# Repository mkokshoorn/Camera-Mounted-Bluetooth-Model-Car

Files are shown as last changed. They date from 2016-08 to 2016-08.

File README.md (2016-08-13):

# Camera Mounted Bluetooth Model Car

Embedded systems six-person project (known as "Wacky Racers") to design and implement a camera mounted, Bluetooth controlled, model car. The project had a requirement that three separate 4-layer boards were developed each with their own microcontroller and communicating over a common I2C bus. An STM32F4 microcontroller was selected for the project.

## Motor Control / Power Board
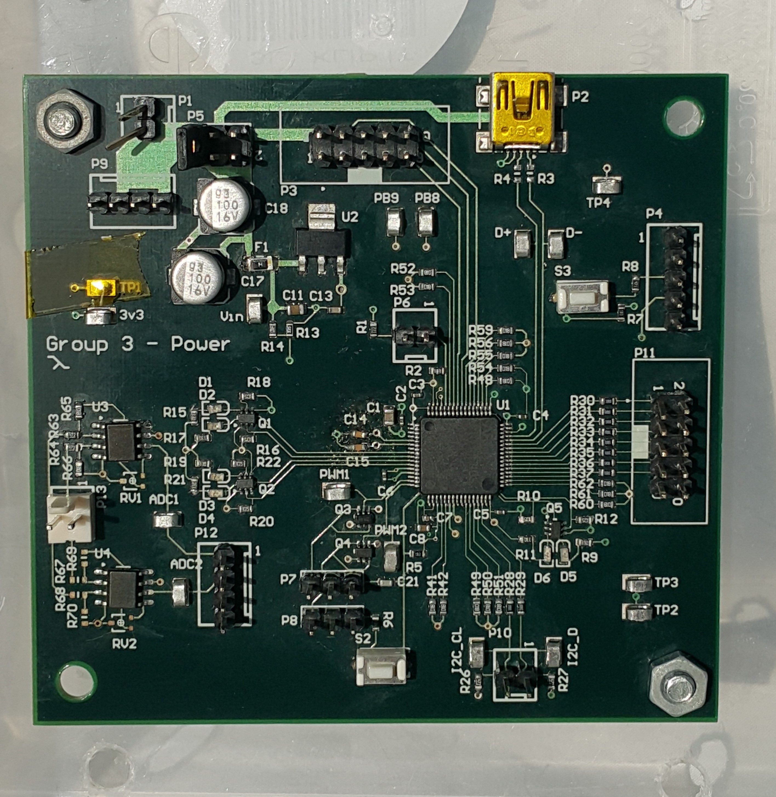
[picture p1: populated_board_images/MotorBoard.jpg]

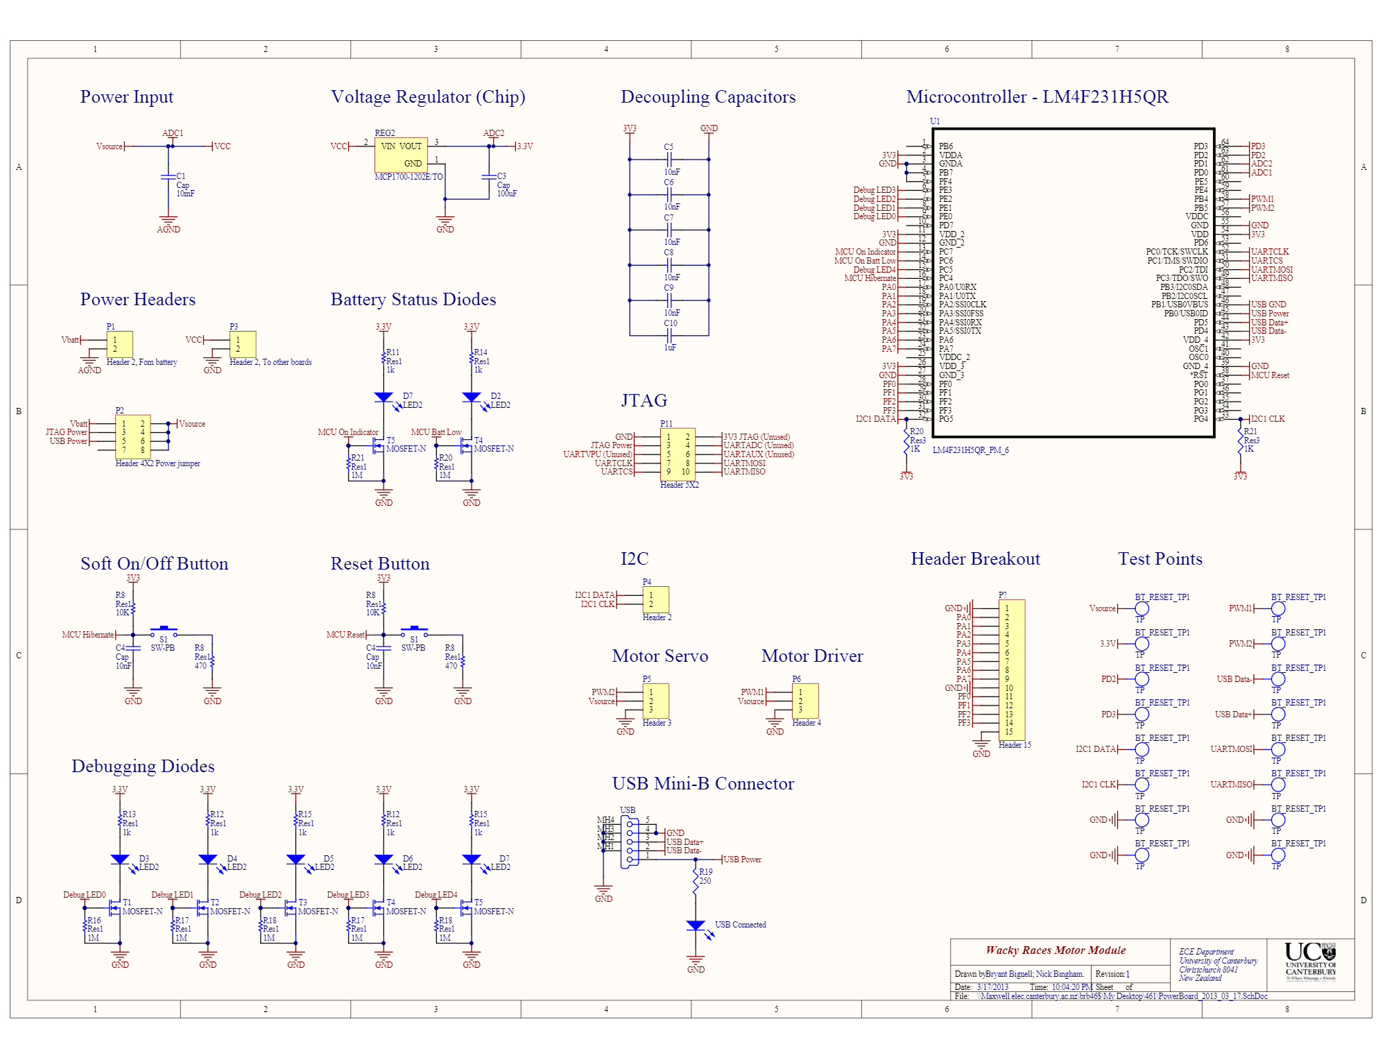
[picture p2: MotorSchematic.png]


## Camera Board
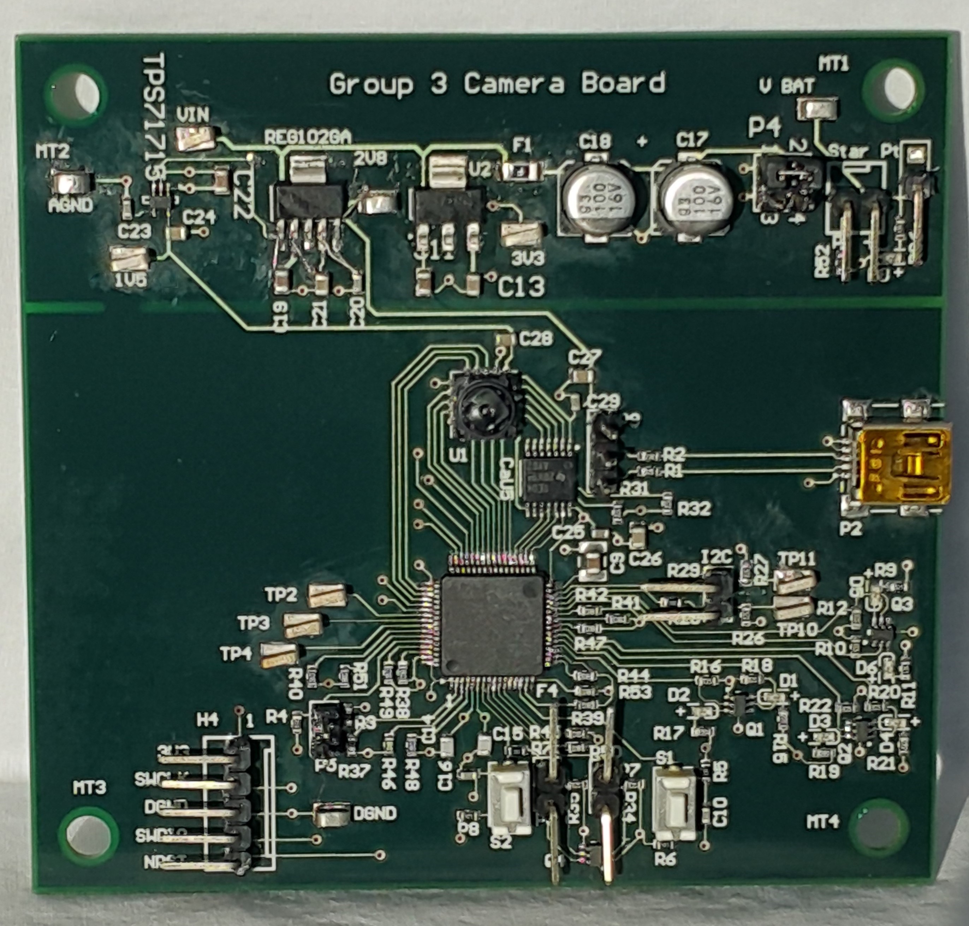
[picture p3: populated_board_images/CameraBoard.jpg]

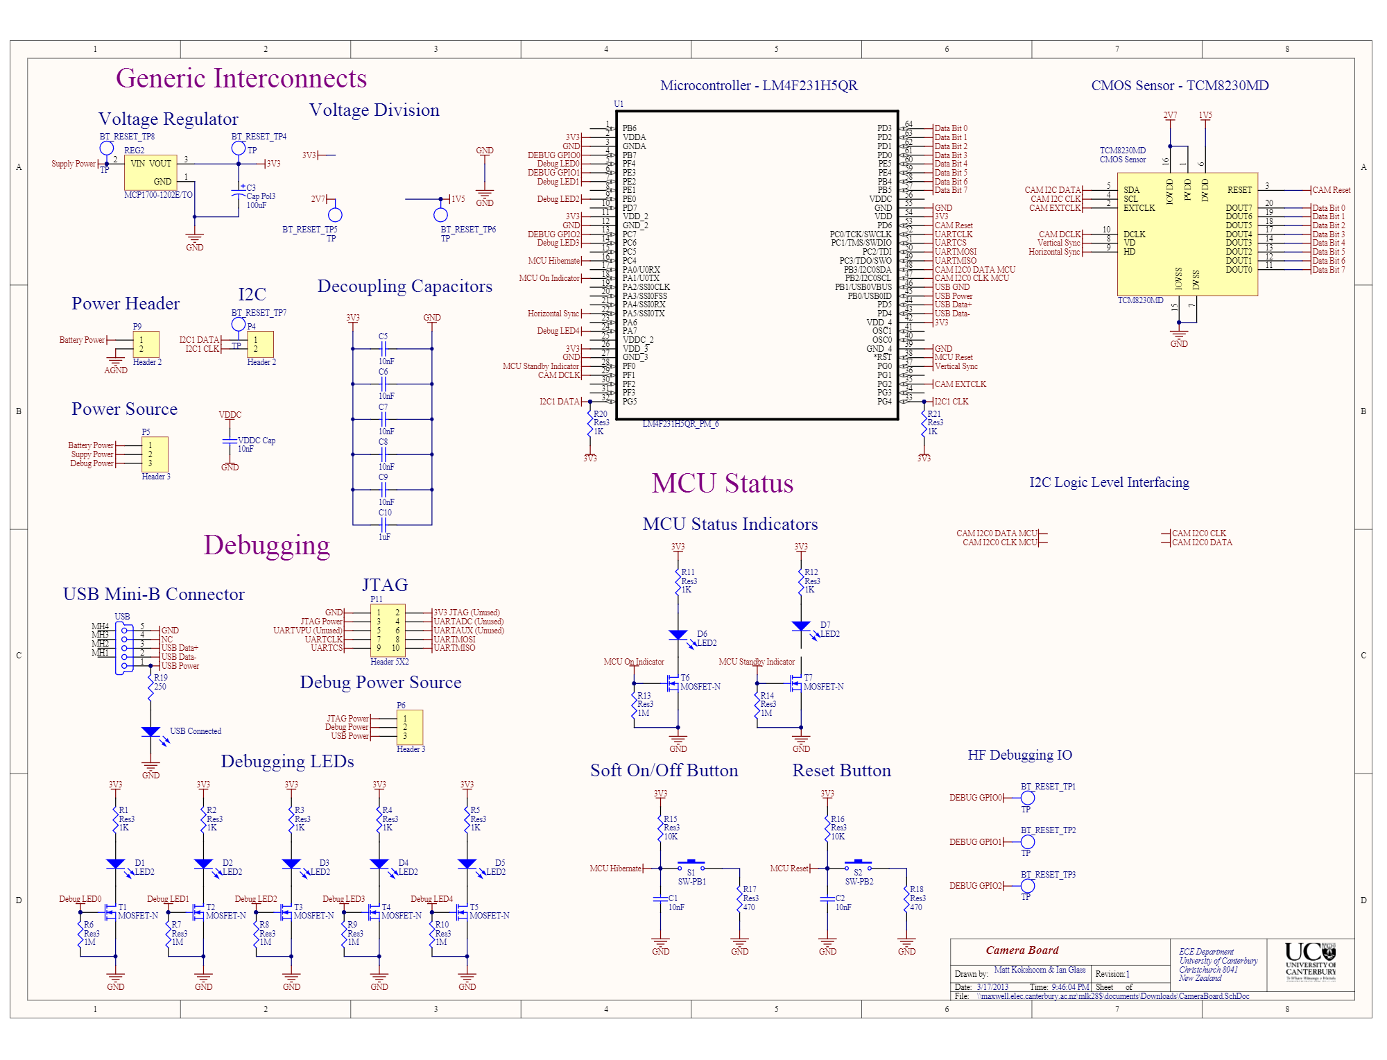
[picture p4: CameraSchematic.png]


## Communications Board
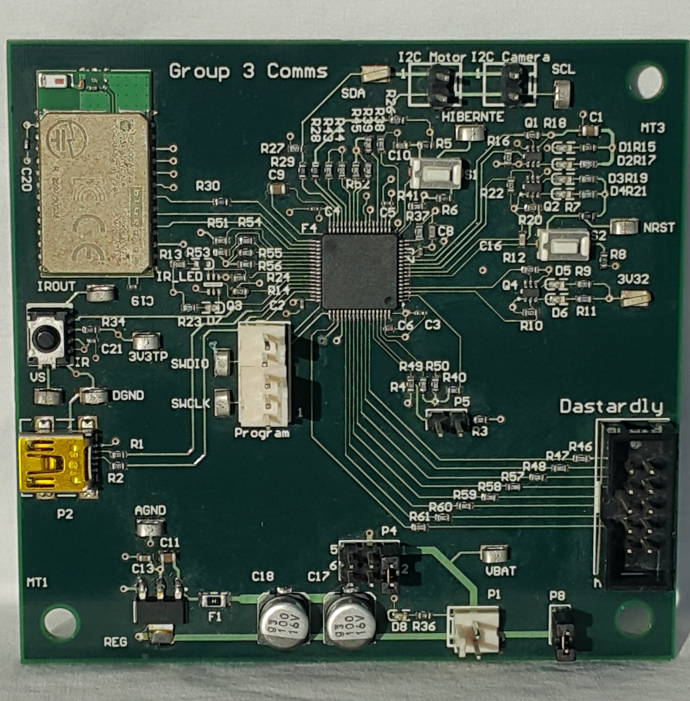
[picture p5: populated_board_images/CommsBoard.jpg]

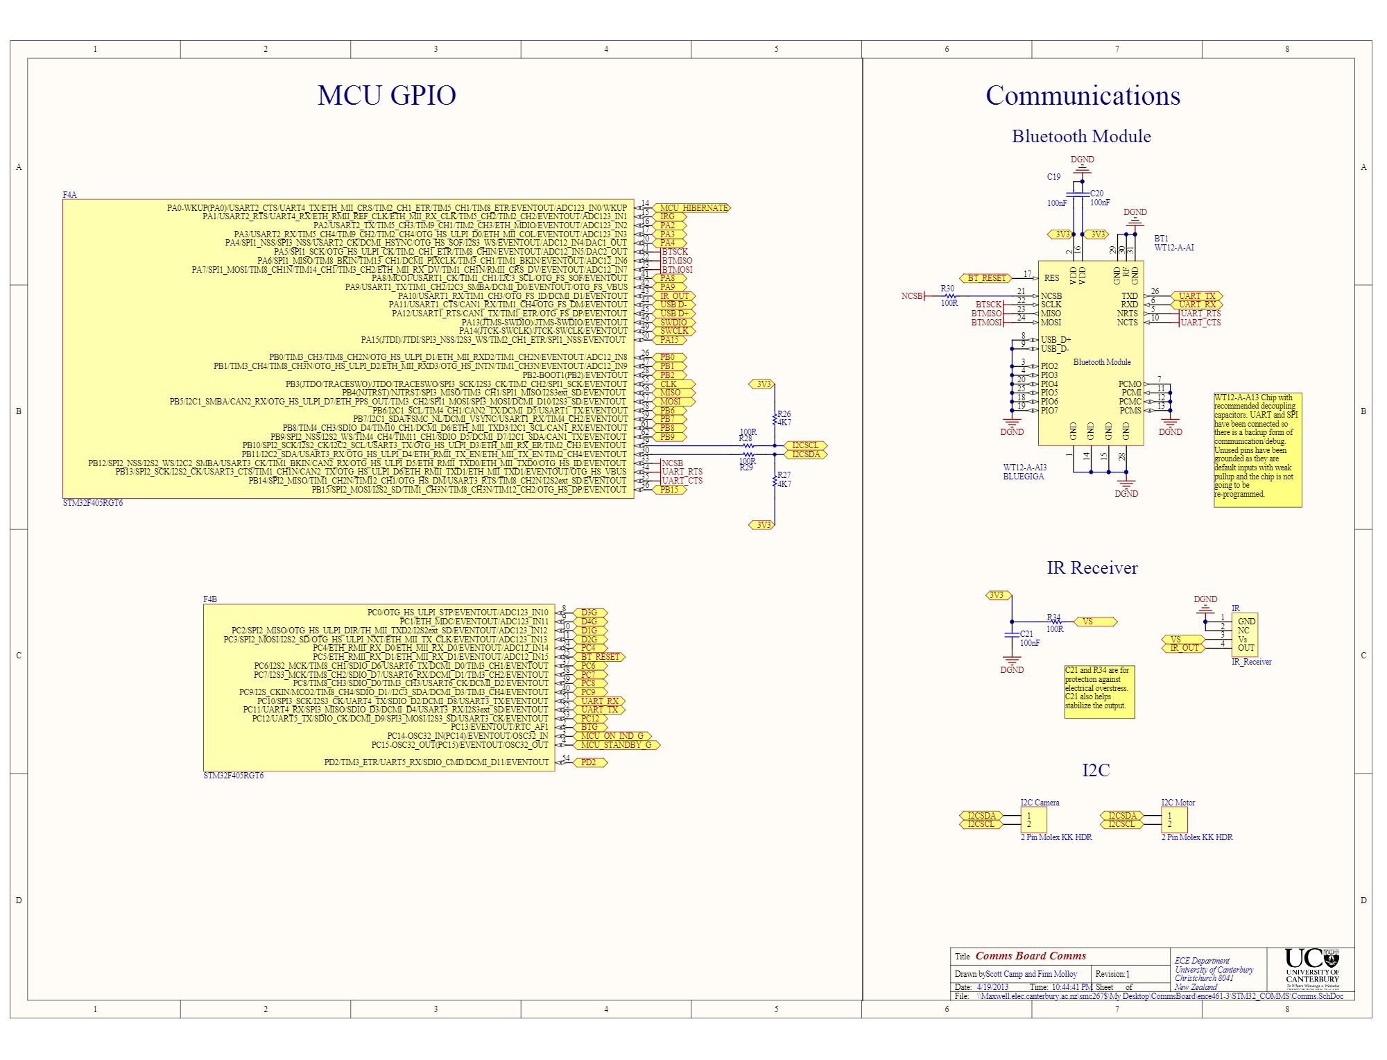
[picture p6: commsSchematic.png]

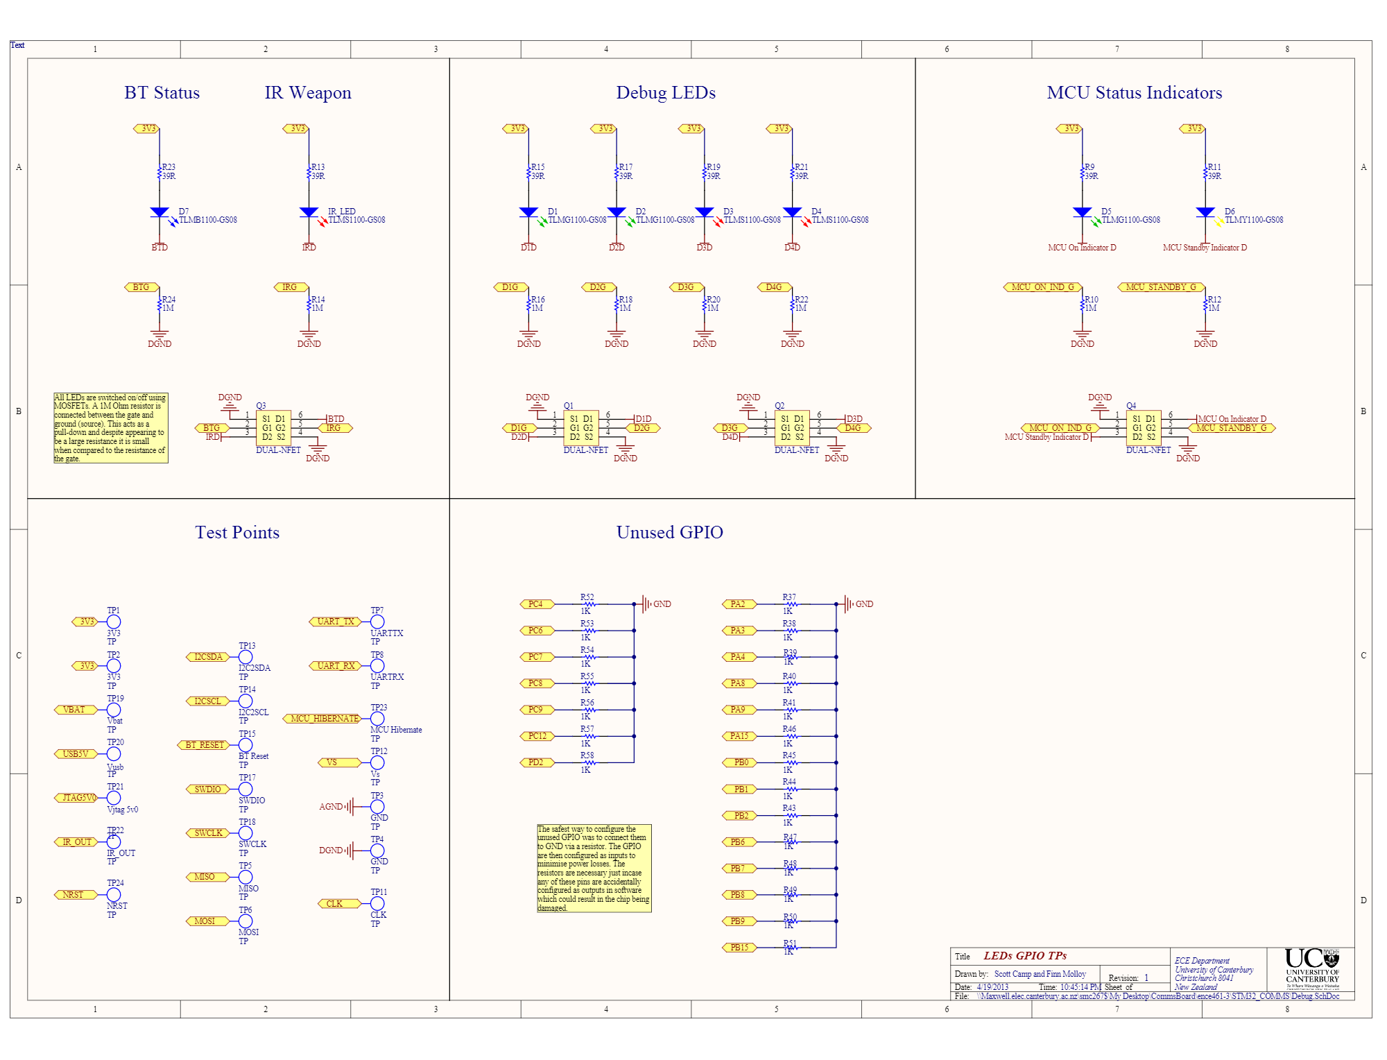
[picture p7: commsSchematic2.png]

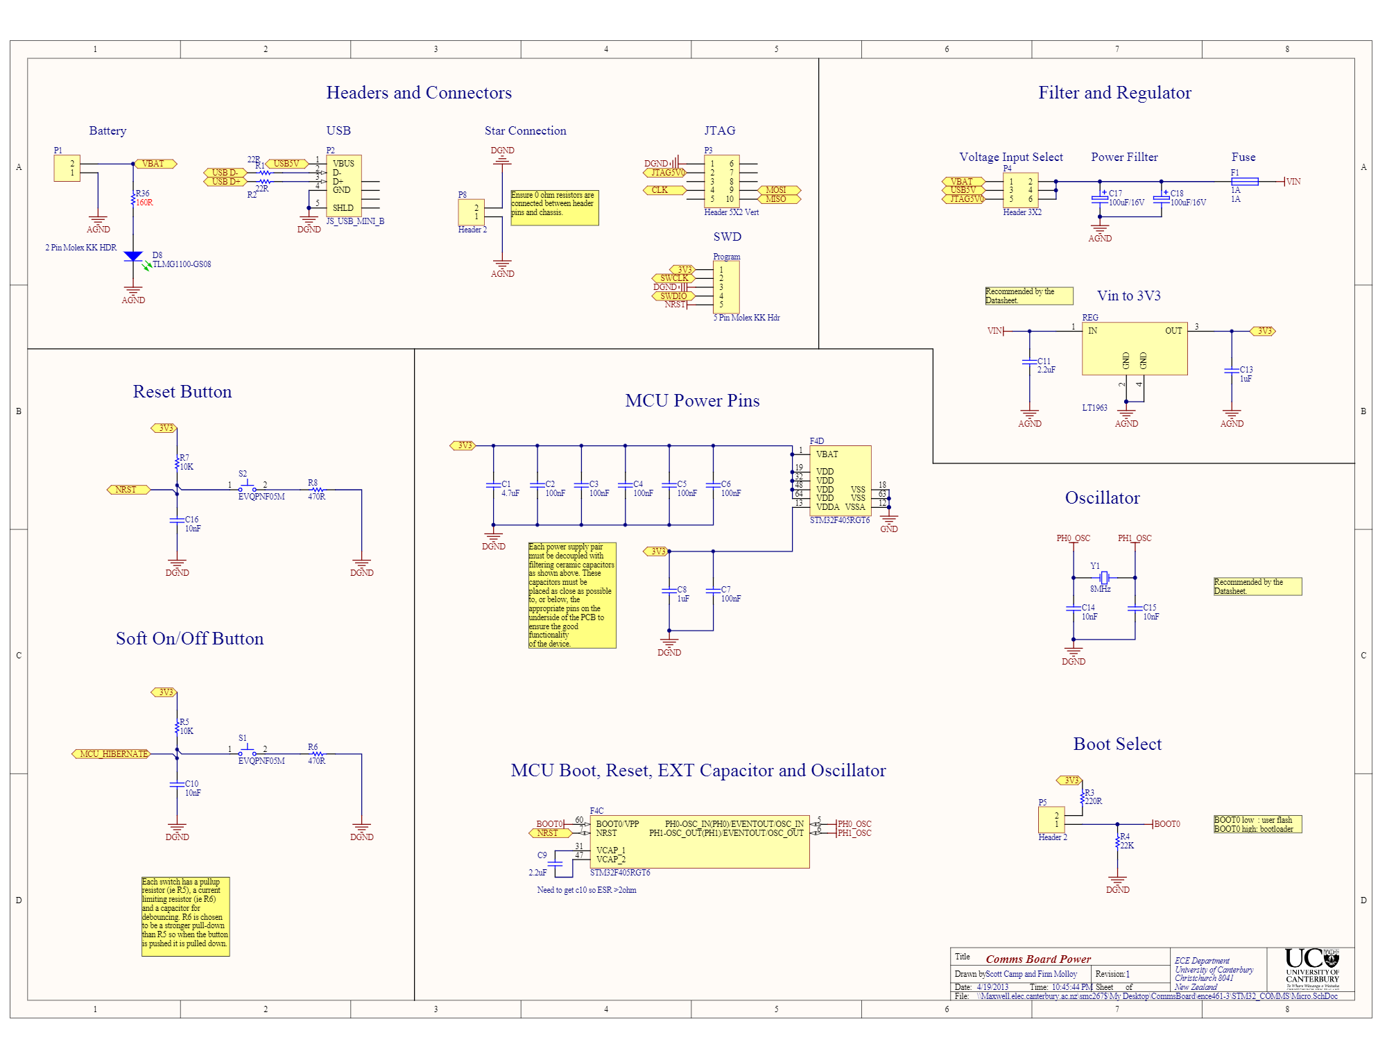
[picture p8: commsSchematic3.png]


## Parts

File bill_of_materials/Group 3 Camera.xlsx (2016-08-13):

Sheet: BOM Report
Bill of Materials |  |  | Camera Board
Source Data From: |  | CameraBoard.SchDoc
Project: |  | Wacky Racers
Variant: |  | None
Creation Date: | 4/4/2013 | 9:10:37 PM
Print Date: | 2013-04-04 | 22:50:31
Production Quantity: | 1
Currency | <none>
Footprint | Comment | LibRef | Designator | Description | Quantity | #Column Name Error:Supplier | Supplier 1 | Supplier Part Number 1
DSO-F2/D6.1 | LED2 | LED2 | D1, D2, D3, D4, D5 | Red LED | 5 |  | Digi-Key | VLMS1300-GS08
TO-92-TO3 | 3V3 Regulator | MCP1700-1202E/TO | REG1 | Low Quiescent Current LDO, 3-Pin TO-92, Extended TemperatureBAG | 1 |  | Digi-Key
 | 2V8 Regulator | NCP502 | REG2 |  | 1 |  | Digi-Key
 | 1V5 Regulator |  | REG3 |  | 1 |  | Digi-Key
BCY-W3/B.8 | MOSFET-N | MOSFET-N | T1, T2, T3, T4, T5,T6 | N-Channel MOSFET | 3 |  | Digi-Key | SI1970DH-T1-E3CT-ND
481900001 | 0481900001 | 0481900001 | USB | USB On-The-Go (OTG) Mini-B Receptacle, Right Angle, SMT, 0.80mm (.031") Pitch, Solder Tabs with Back Cover, Recessed Type | 1 |  | Digi-Key | A31727CT-ND
3.5X2.8X1.9 | LED3 | LED3 | USB Connected/MCU Status | Green LED | 2 |  | Digi-Key | VLMTG1300-GS08
TODO | OSC | OSC | Y1 | Oscillator | 1 |  | Digi-Key | 535-10088-2-ND
C1210 | Cap Semi | Cap Semi | C1, C2, C5, C6, C7, C8, C9, C10, C11, C12, C13, C14, C15, C16, VDDC Cap | Capacitor (Semiconductor SIM Model) | 15 |  | ECE Dept Stock
C0805 | Cap Pol3 | Cap Pol3 | C3, C17, C17 | Polarized Capacitor (Surface Mount) | 3 |  | ECE Dept Stock
HDR1X2 | Header 2 | Header 2 | I2C Header, PWR Header | Header, 2-Pin | 2 |  | ECE Dept Stock
J1-0603 | Res3 | Res3 | R1, R2, R3, R4, R6, R7, R8, R9, R11, R12, R13, R14, R15, R16, R17, R18, R19, R20, R21 | Resistor | 19 |  | ECE Dept Stock
PM64 | LM4F231H5QR_PM_6 | LM4F231H5QR_PM_6 | U1 | Cortex M4 | 1 |  | Element 14 | 2246242
TODO | Logic Shifter | LS1 | LS1 | Logic Inteface between Camera and MCU | 1 |  | Element 14 | TXS0104ED
FSM2JSMA | Switch | SW_FSM2JSMA | SW1, SW2 | TE CONNECTIVITY / ALCOSWITCH - FSM2JSMA - SWITCH, SPST, 0.05A, 24VDC, SMD | 2 |  | Farnell | 3801287
TCM8230MD | TCM8230MD | TCM8230MD | U? | Toshiba I2C Camera | 1 |  | Spark Fun
 |  |  |  |  | 56
Approved |  | Notes

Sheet: Project Information
Project Full Path | Free Documents
Project Filename | Free Documents
Variant Name | None
Data-Source Filename | CameraBoard (1).SchDoc
Data-Source Full Path | \\Maxwell.elec.canterbury.ac.nz\mlk28$\My Desktop\CameraBoard (1).SchDoc
Title | Camera Board
Total Quantity | 63
Report Time | 9:10:37 PM
Report Date | 4/4/2013
Report Date & Tine | 4/4/2013 9:10:37 PM
Output Name | Bill of Materials
Output Type | BOM_PartType
Output Generator Name | BOM
Output Generator Description | Bill of Materials

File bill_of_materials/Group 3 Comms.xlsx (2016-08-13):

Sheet: BOM Report
Bill of Materials |  |  | Comms Microcontroller and General
Source Data From: |  | WackyRacersComms.PrjPcb
Project: |  | WackyRacersComms.PrjPcb
Variant: |  | None
Creation Date: | 4/4/2013 | 8:41:36 PM
Print Date: | 2013-04-04 | 20:59:11
Production Quantity: | 1
Currency | <none>
Footprint | Comment | LibRef | Designator | Description | Quantity | Supplier 1 | Supplier Part Number 1 | Supplier 2 | Supplier Part Number 2 | Manufacturer | Manufacturer PN
WT12_Bluetooth | BT Chip | UN_WT12_Bluetooth | BT1 | BLUEGIGA - WT12-A-AI - BLUETOOTH MOD, V2.1, CLASS 2, 3MBPS | 1 | Farnell | 1704779 |  |  | BLUEGIGA
C1210 | Cap Semi | Cap Semi | C1, C2, C4, C5, C6, C7, C8, C9, C10, C11, C12, C13, C14, C15 | Capacitor (Semiconductor SIM Model) | 14 | ECE Dept Stock
C0805 | Cap Pol3 | Cap Pol3 | C3 | Polarized Capacitor (Surface Mount) | 1 | ECE Dept Stock
HDR1X3 | Header 3 | Header 3 | Debug Header, SRC Header | Header, 3-Pin | 2 | ECE Dept Stock
TODO | Green LED | Green LED | GREEN_LED-1, GREEN_LED-2, GREEN_LED-3, GREEN_LED-4, GREEN_LED-5, GREEN_LED-6, GREEN_LED-7, GREEN_LED-8, GREEN_LED-9 | GREEN_LED | 9 | Digi-Key | VLMTG1300-GS08 |  |  | Vishay | VLMTG1300-GS08
HDR1X2 | Header 2 | Header 2 | I2C Header, PWR Header | Header, 2-Pin | 2 | ECE Dept Stock
DSO-F2/D6.1 | IR Led | IRLed | IR LED | Typical RED, GREEN, YELLOW, AMBER GaAs LED | 1 | ECE Dept Stock
TODO | IR | IR | IR Reveiver | IR | 1 | Element 14 | 2251351 |  |  | Vishay | TSOP35438TR
HDR2X5 | Header 5X2 | Header 5X2 | JTAG Header | Header, 5-Pin, Dual row | 1 | ECE Dept Stock
PM64 | LM4F231H5QR_PM_6 | LM4F231H5QR_PM_6 | Micro_1 | M4 Microcontroller | 1 | Element 14 | 2246242 |  |  | Texas Instruments | LM4F231H5QRFIG
TODO | DUAL N-FET | ALD110814SCL | N-FET-1, N-FET-2, N-FET-3, N-FET-4 | QUAD N-FET | 4 | Digi-key | SI1970DH-T1-E3CT-ND
J1-0603 | Res3 | Res3 | R1, R2, R3, R4, R6, R7, R8, R9, R11, R12, R13, R14, R15, R16, R17, R18, R19, R20, R21, R22, R23, R24, R25, R26 | Resistor | 24 | ECE Dept Stock
TODO | 3V3 Regulator | 3V3 Reg | Reg | 3V3 Regulator | 1 | Digi-Key | 296-11021-1-ND
FSM2JSMA | Switch | SW_FSM2JSMA | SW1, SW2 | TE CONNECTIVITY / ALCOSWITCH - FSM2JSMA - SWITCH, SPST, 0.05A, 24VDC, SMD | 2 | Farnell | 3801287 | Digi-Key | 450-1757-6-ND | TE CONNECTIVITY / ALCOSWITCH
TODO | OSC | OSC | Y1 | Oscillator | 1 | Digi-Key | 535-10088-2-ND |  |  | Abracon Corporation | ASV-60.000MHZ-E-T
481900001 | USB-MINI_B | 0481900001 | USB | USB On-The-Go (OTG) Mini-B Receptacle, Right Angle, SMT, 0.80mm (.031") Pitch, Solder Tabs with Back Cover, Recessed Type | 1 | Digi-Key | A31727CT-ND
 |  |  |  |  | 66
Approved |  | Notes

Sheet: Project Information
Project Full Path | \\Maxwell.elec.canterbury.ac.nz\smc267$\My Desktop\ENEL461\WackyRacersComms.PrjPcb
Project Filename | WackyRacersComms.PrjPcb
Variant Name | None
Data-Source Filename | WackyRacersComms.PrjPcb
Data-Source Full Path | \\Maxwell.elec.canterbury.ac.nz\smc267$\My Desktop\ENEL461\WackyRacersComms.PrjPcb
Title | Comms Microcontroller and General
Total Quantity | 63
Report Time | 8:41:36 PM
Report Date | 4/4/2013
Report Date & Tine | 4/4/2013 8:41:36 PM
Output Name | Bill of Materials
Output Type | BOM_PartType
Output Generator Name | BOM
Output Generator Description | Bill of Materials

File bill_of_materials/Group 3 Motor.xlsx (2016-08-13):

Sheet: BOM Report
Bill of Materials |  |  | Wacky Races Motor Module
Source Data From: |  | PowerBoard_bryant_2013_04_04.SchDoc
Project: |  | Free Documents
Variant: |  | None
Creation Date: | 4/4/2013 | 7:29:26 PM
Print Date: | 2013-04-04 | 20:43:14
Production Quantity: | 1
Currency | <none>
Footprint | Comment | LibRef | Designator | Description | Quantity | #Column Name Error:Supplier | Supplier 1 | Supplier Part Number 1 | Supplier 2 | Supplier Part Number 2 | #Column Name Error:Manufacturer | #Column Name Error:Manufacturer PN
RAD-0.3 | Cap | Cap | C1, C3, C4, C4 | Capacitor | 4 |  | ECE Dept Stock | _
0805 | Cap Semi | Cap Semi | C5, C6, C7, C8, C9, C10 | Capacitor (Semiconductor SIM Model) | 6 |  | ECE Dept Stock | _
DSO-F2/D6.1 | LED2 | LED2 | D1, D2, D3, D4, D5, D6, D7 | Typical RED, GREEN, YELLOW, AMBER GaAs LED | 6 |  | Digi-Key | VLMB1300-ND
HDR1X2 | Header 2, Fom battery | Header 2 | P1, P2, P3, P4, P5, P6, P7, P11 | Header | 8 |  | ECE Dept Stock | _
1206 | Res1 | Res1 | R8, R8, R8, R8, R8, R8, R11, R12, R12, R13, R14, R15, R16, R17, R17, R18, R20, R21 | Resistor | 18 |  | ECE Dept Stock | _
RAD-0.3 | Res3 | Res3 | R19, R20, R21 | Resistor | 3 |  | ECE Dept Stock | _
TO-92-TO3 | MCP1700-1202E/TO | MCP1700-1202E/TO | REG2 | Low Quiescent Current LDO, 3-Pin TO-92, Extended TemperatureBAG | 1 |  | Digi-Key | 296-11021-1-ND
SPST-2 | SW-PB | SW-PB | S1, S2 | Switch | 2 |  | Digi-Key | 450-1130-ND
SC-70 | MOSFET-N | MOSFET-N | T7, T8 | Complementary Low-Threshold MOSFET Pair | 2 |  | Digi-Key | SI1555DL-T1-E3CT-ND
BCY-W3/B.8 | MOSFET-N | MOSFET-N | T1, T2, T3, T4, T5, T6, | DUAL N-CHANNEL | 2 |  | Digi-Key | SI1970DH-T1-E3CT-ND
E3 | MOSFET-P | MOSFET-P | T9, T10 | P-Channel MOSFET | 0 |  | Digi-Key | SI1555DL-T1-E3CT-ND
 | OSCILLATOR | OSCILLATOR | K1 | OSCILLATOR | 1 |  | Digi-Key | 535-10088-2-ND
PM64 | LM4F231H5QR_PM_6 | LM4F231H5QR_PM_6 | U1 | CORTEX M4 | 1 |  | ELEMENT14 | 2246424
USB | 0481900001 | 0481900001 | USB | USB On-The-Go (OTG) Mini-B Receptacle, Right Angle, SMT, 0.80mm (.031") Pitch, Solder Tabs with Back Cover, Recessed Type | 1 |  | Digi-Key | A31727CT-ND
 |  |  |  |  | 55
Approved |  | Notes

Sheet: Project Information
Project Full Path | Free Documents
Project Filename | Free Documents
Variant Name | None
Data-Source Filename | PowerBoard_bryant_2013_04_04.SchDoc
Data-Source Full Path | \\Maxwell.elec.canterbury.ac.nz\brb46$\My Desktop\461\PowerBoard_bryant_2013_04_04.SchDoc
Title | Wacky Races Motor Module
Total Quantity | 61
Report Time | 7:29:26 PM
Report Date | 4/4/2013
Report Date & Tine | 4/4/2013 7:29:26 PM
Output Name | Bill of Materials
Output Type | BOM_PartType
Output Generator Name | BOM
Output Generator Description | Bill of Materials

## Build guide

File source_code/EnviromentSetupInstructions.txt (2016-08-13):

1) Download Attolic Embedded Workbench (This is used for programming/debugging via the SWD link)
	http://www.atollic.com/index.php/download/truestudio-for-arm 

	- Open Appropriate Workspace I have set up.

		- Comms
		- Camera
		- Motor 
		- Dev Board

Programming Hardware setup:

	- Grab a Dev board and some female to female cords (got heaps)
	- Find the SWD header 6 pin header (Calling the end with the dot 1):

		from Dev board to Wacky Racers boards:
		- Pin 1/??? 	to ??? (Dev Board:GND)    ------- N/A
		- Pin 2/T_JTCK 	to SWCLK (Dev Board:PA14)
		- Pin 3/GND	to DGND (Dev Board:GND)
		- Pin 4/T_JTMS  to SWDIO (Dev Board:PA13)
		- Pin 5/T_NRST 	to NRST (Dev Board:NRST)
		- Pin 6/T_SWO 	to GND (Dev Board:PB3)    ------- N/A

2) Download and Install Tera Term (This is used for uart communication with the chip)
	- Go New Connection -> Serial Connection -> USB Serial Port (COMX)
	- Setup -> Serial Port Baud Rate -> 115200 .
	- Setup -> Terminal -> Make syre recieve and transmit are 'CR' under new-line and encavble local echo.

	To Enable Serial Comms with MCU enter the following in the terminal (By \n I mean enter) 'm\n','3\n','9\n','1\n','1\n','2\n' then '(2)'

	Ensure the following hardware Hardware- Connection (DEV BOARD) to Bus Pirate 
		- MISO (bus Pirate) to PA2 (Usart2 Tx) (SCL)
		- MOSI (bus pirate) to PA3 (Usart2 Rx)
		- GND to GND

3)	Some Notes about Common Code:

	- I have developed some code for printing to the terminal via the dev board and will
	  port this out 64 pin controller when we begin programming. (Thurday Week 4).

	- I am working on I2C code between two dev boards and then I will port to new MCU too. (Thursday Week 4).

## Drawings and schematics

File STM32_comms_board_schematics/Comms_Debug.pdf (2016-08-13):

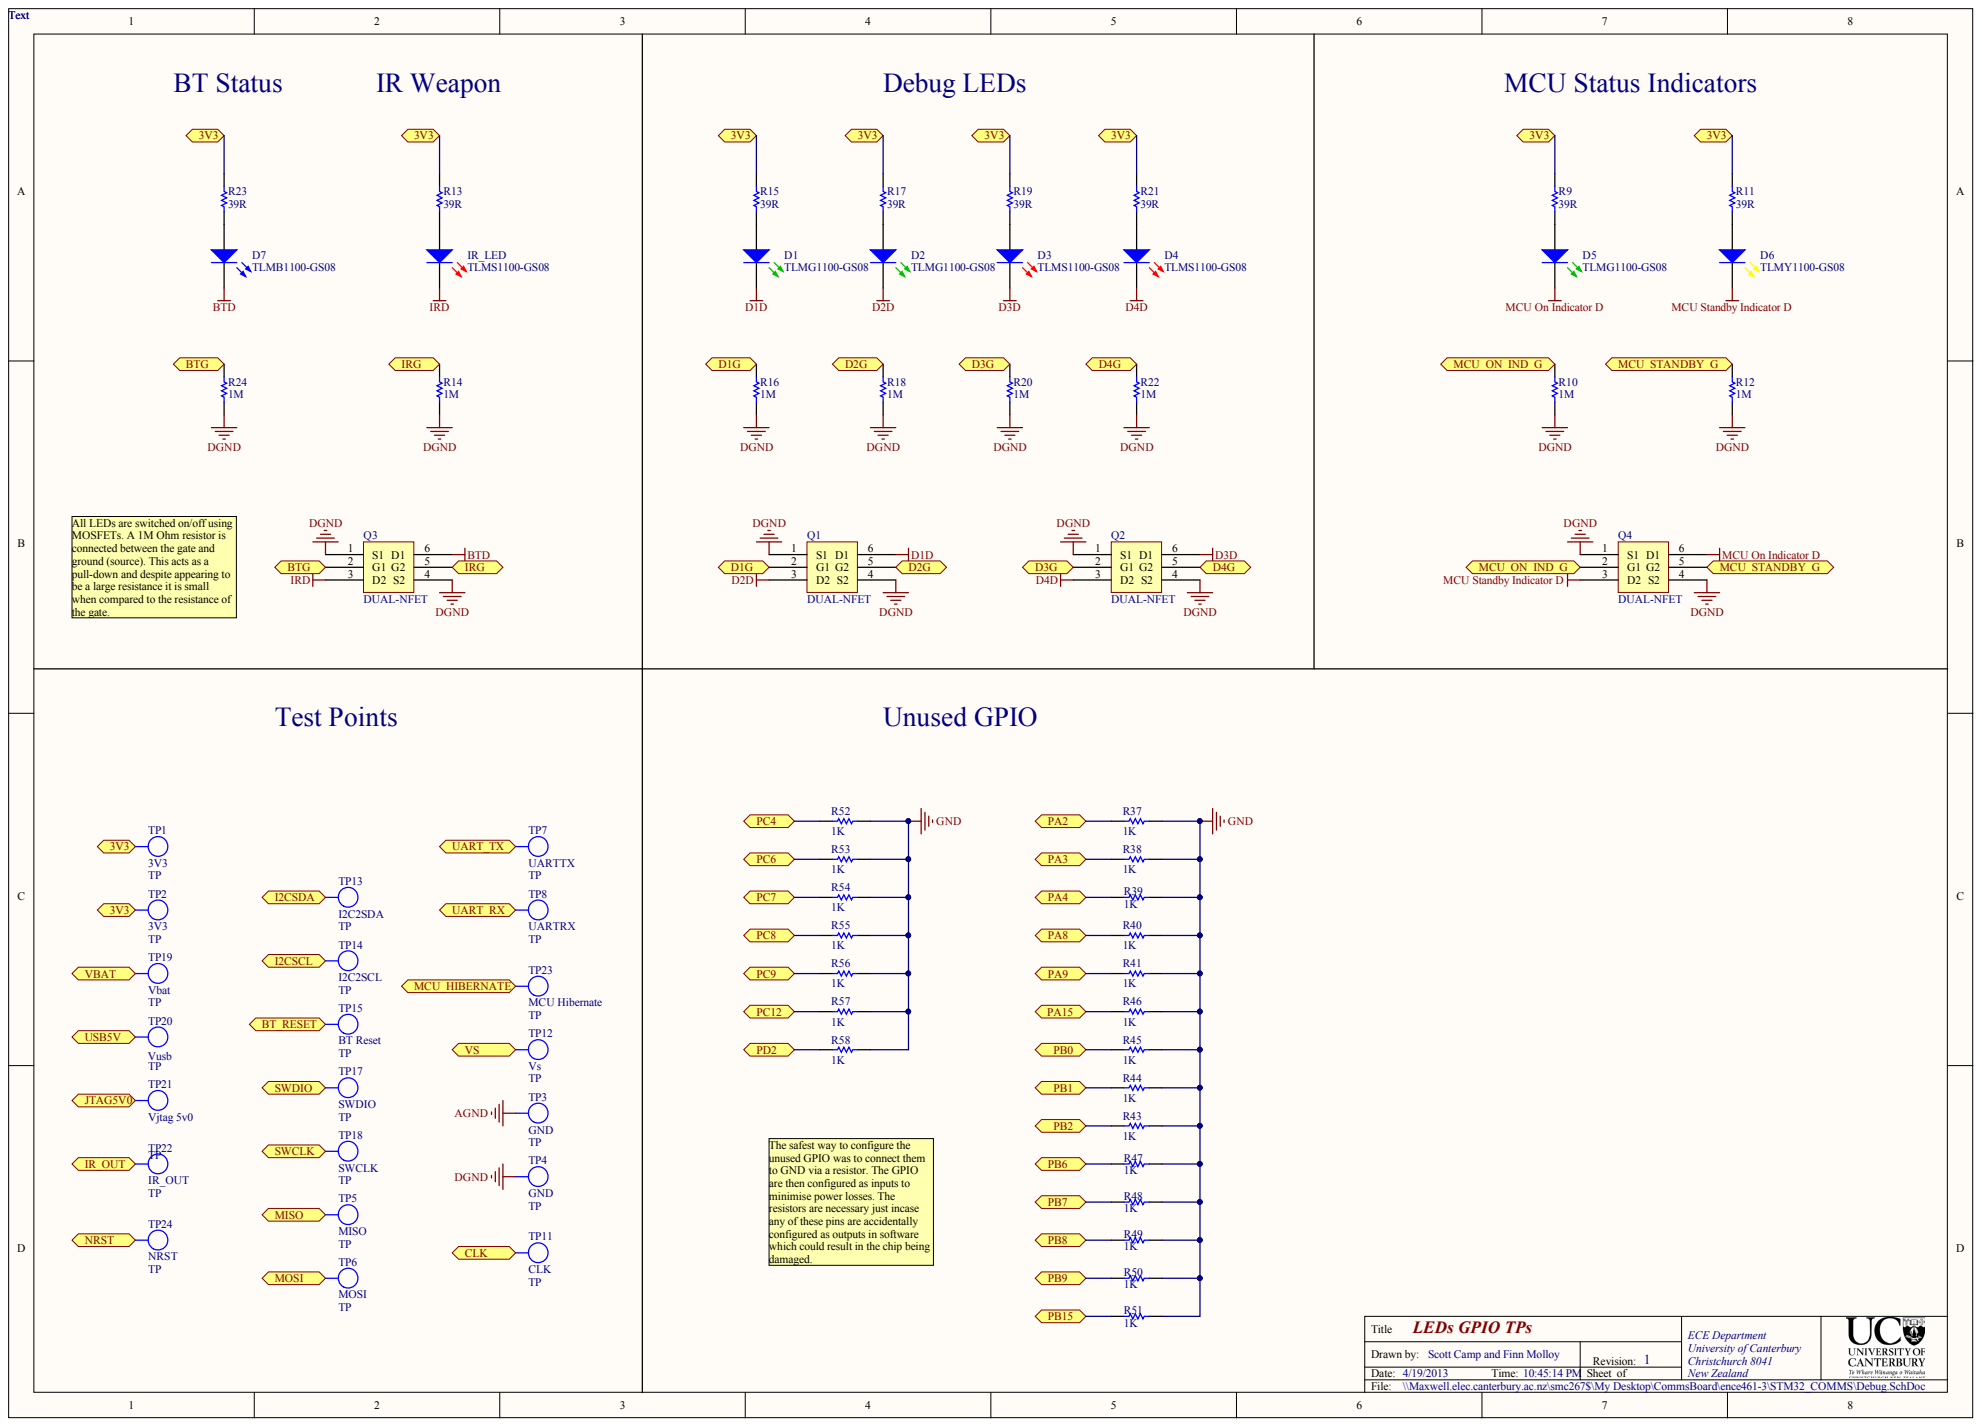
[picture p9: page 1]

All LEDs are switched on/off using
MOSFETs. A 1M Ohm resistor is
connected between the gate and
ground (source). This acts as a
pull-down and despite appearing to
be a large resistance it is small
when compared to the resistance of
the gate.

The safest way to configure the
unused GPIO was to connect them
to GND via a resistor. The GPIO
are then configured as inputs to
minimise power losses. The
resistors are necessary just incase
any of these pins are accidentally
configured as outputs in software
which could result in the chip being
damaged.

LEDs GPIO TPs Title | ECE Department University of Canterbury Christchurch 8041 New Zealand

Drawn by: Scott Camp and Finn Molloy 10:45:14 PM | Revision: 1 4/19/2013
Date: Time: | Sheet of

\\Maxwell.elec.canterbury.ac.nz\smc267$\My Desktop\CommsBoard\ence461-3\STM32_COMMS\Debug.SchDoc

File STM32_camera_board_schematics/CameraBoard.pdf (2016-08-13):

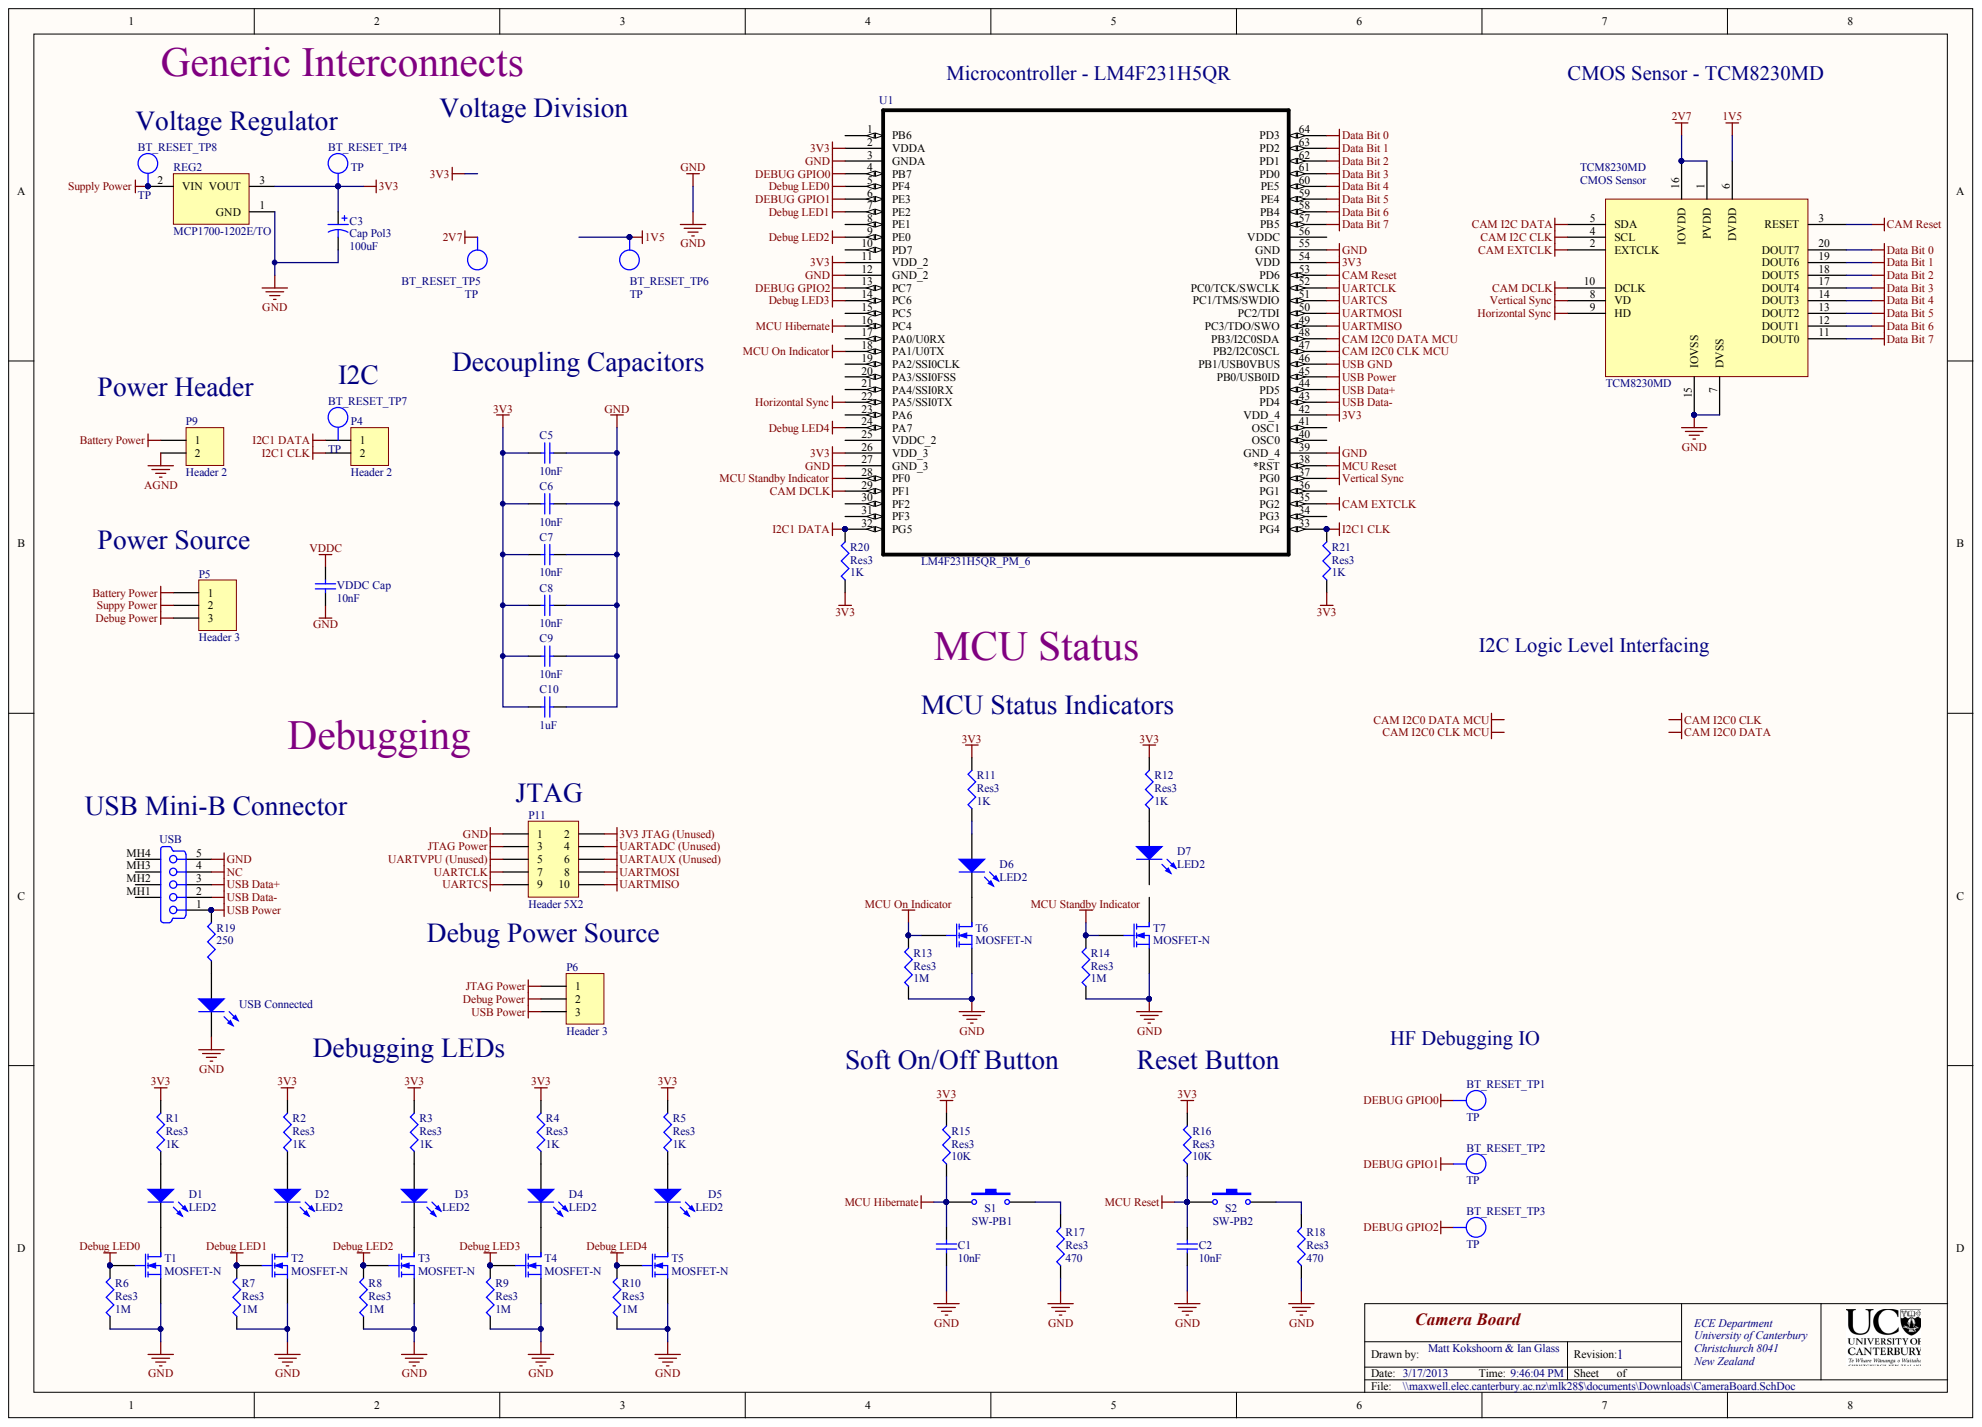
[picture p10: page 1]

JTAG USB Mini-B Connector

Soft On/Off Button

Matt Kokshoorn & Ian Glass Drawn by: | Revision: 1

Date: 3/17/2013 Time: 9:46:04 PM | Sheet of

\\maxwell.elec.canterbury.ac.nz\mlk28$\documents\Downloads\CameraBoard.SchDoc

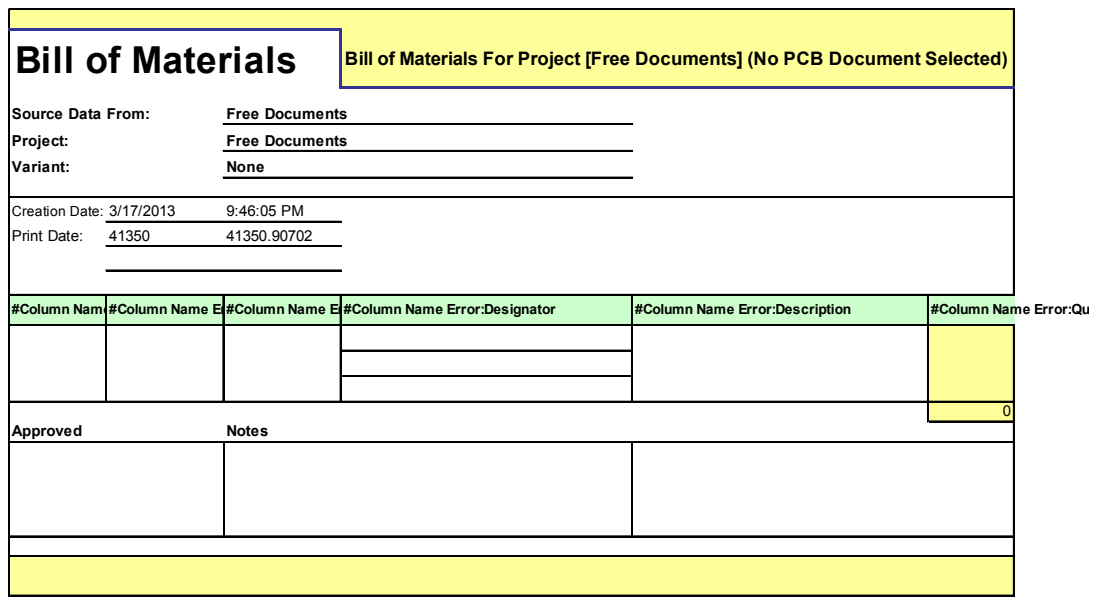
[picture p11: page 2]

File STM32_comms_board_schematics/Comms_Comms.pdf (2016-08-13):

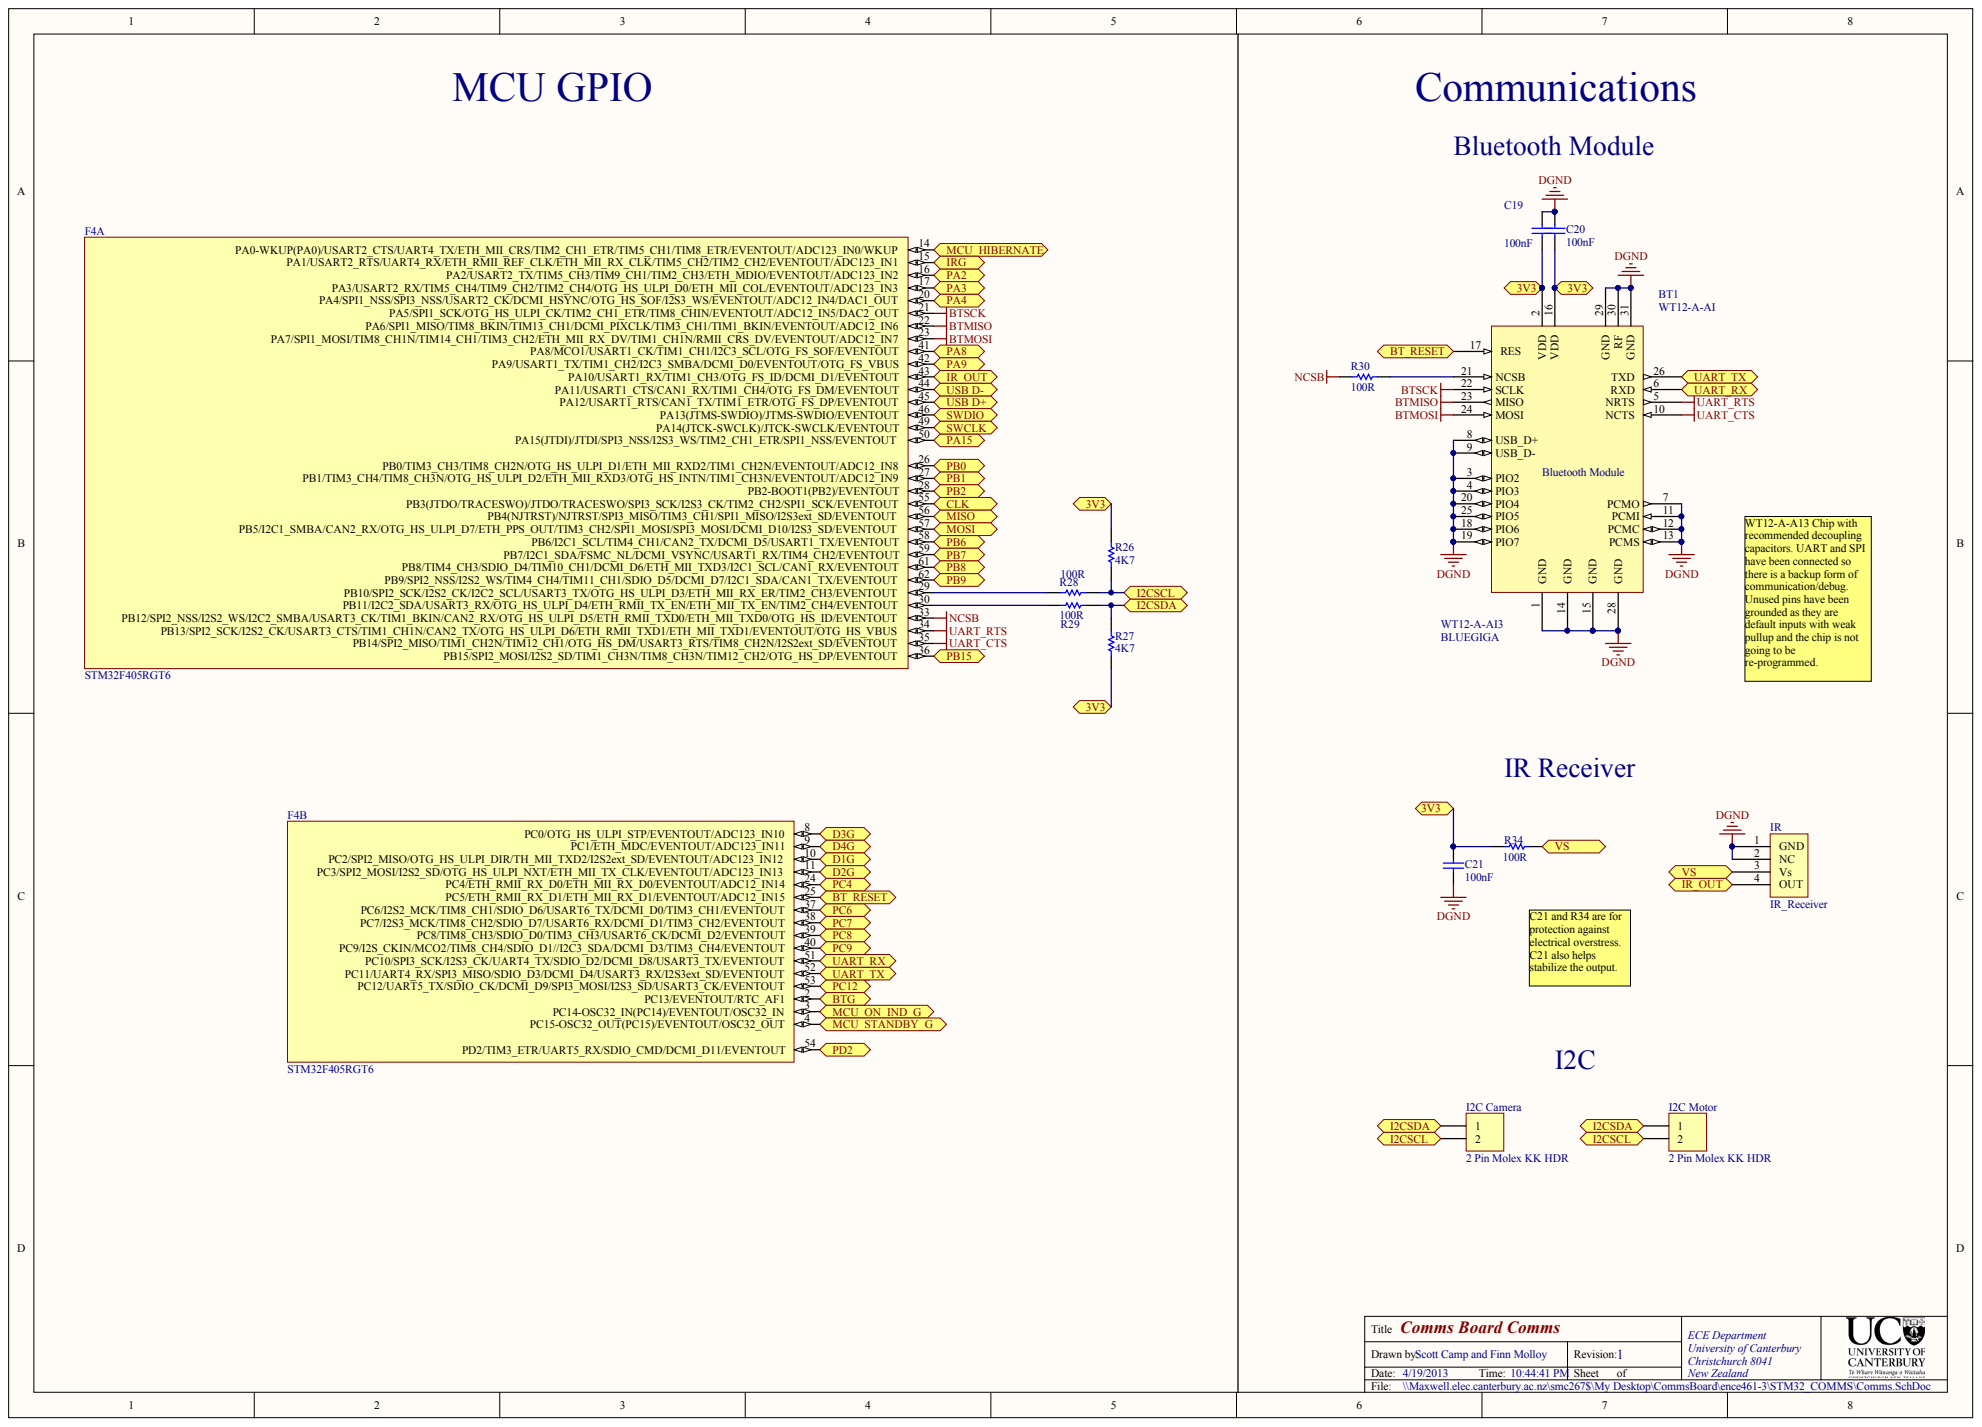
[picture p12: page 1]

2 3 | 5
2 4 | 1 0

Comms Board Comms Title | ECE Dep a rtme n t Univ e rsity of Ca nte rb u ry Ch ristc h u r c h 8 0 4 1 New Ze ala n d

Drawn b y S : c ott Camp an d Finn Mollo y | Re visio n : 1

Date : 4/1 9/2 0 1 3 Time : 1 0:4 4:4 1 P M | S h e e t o f

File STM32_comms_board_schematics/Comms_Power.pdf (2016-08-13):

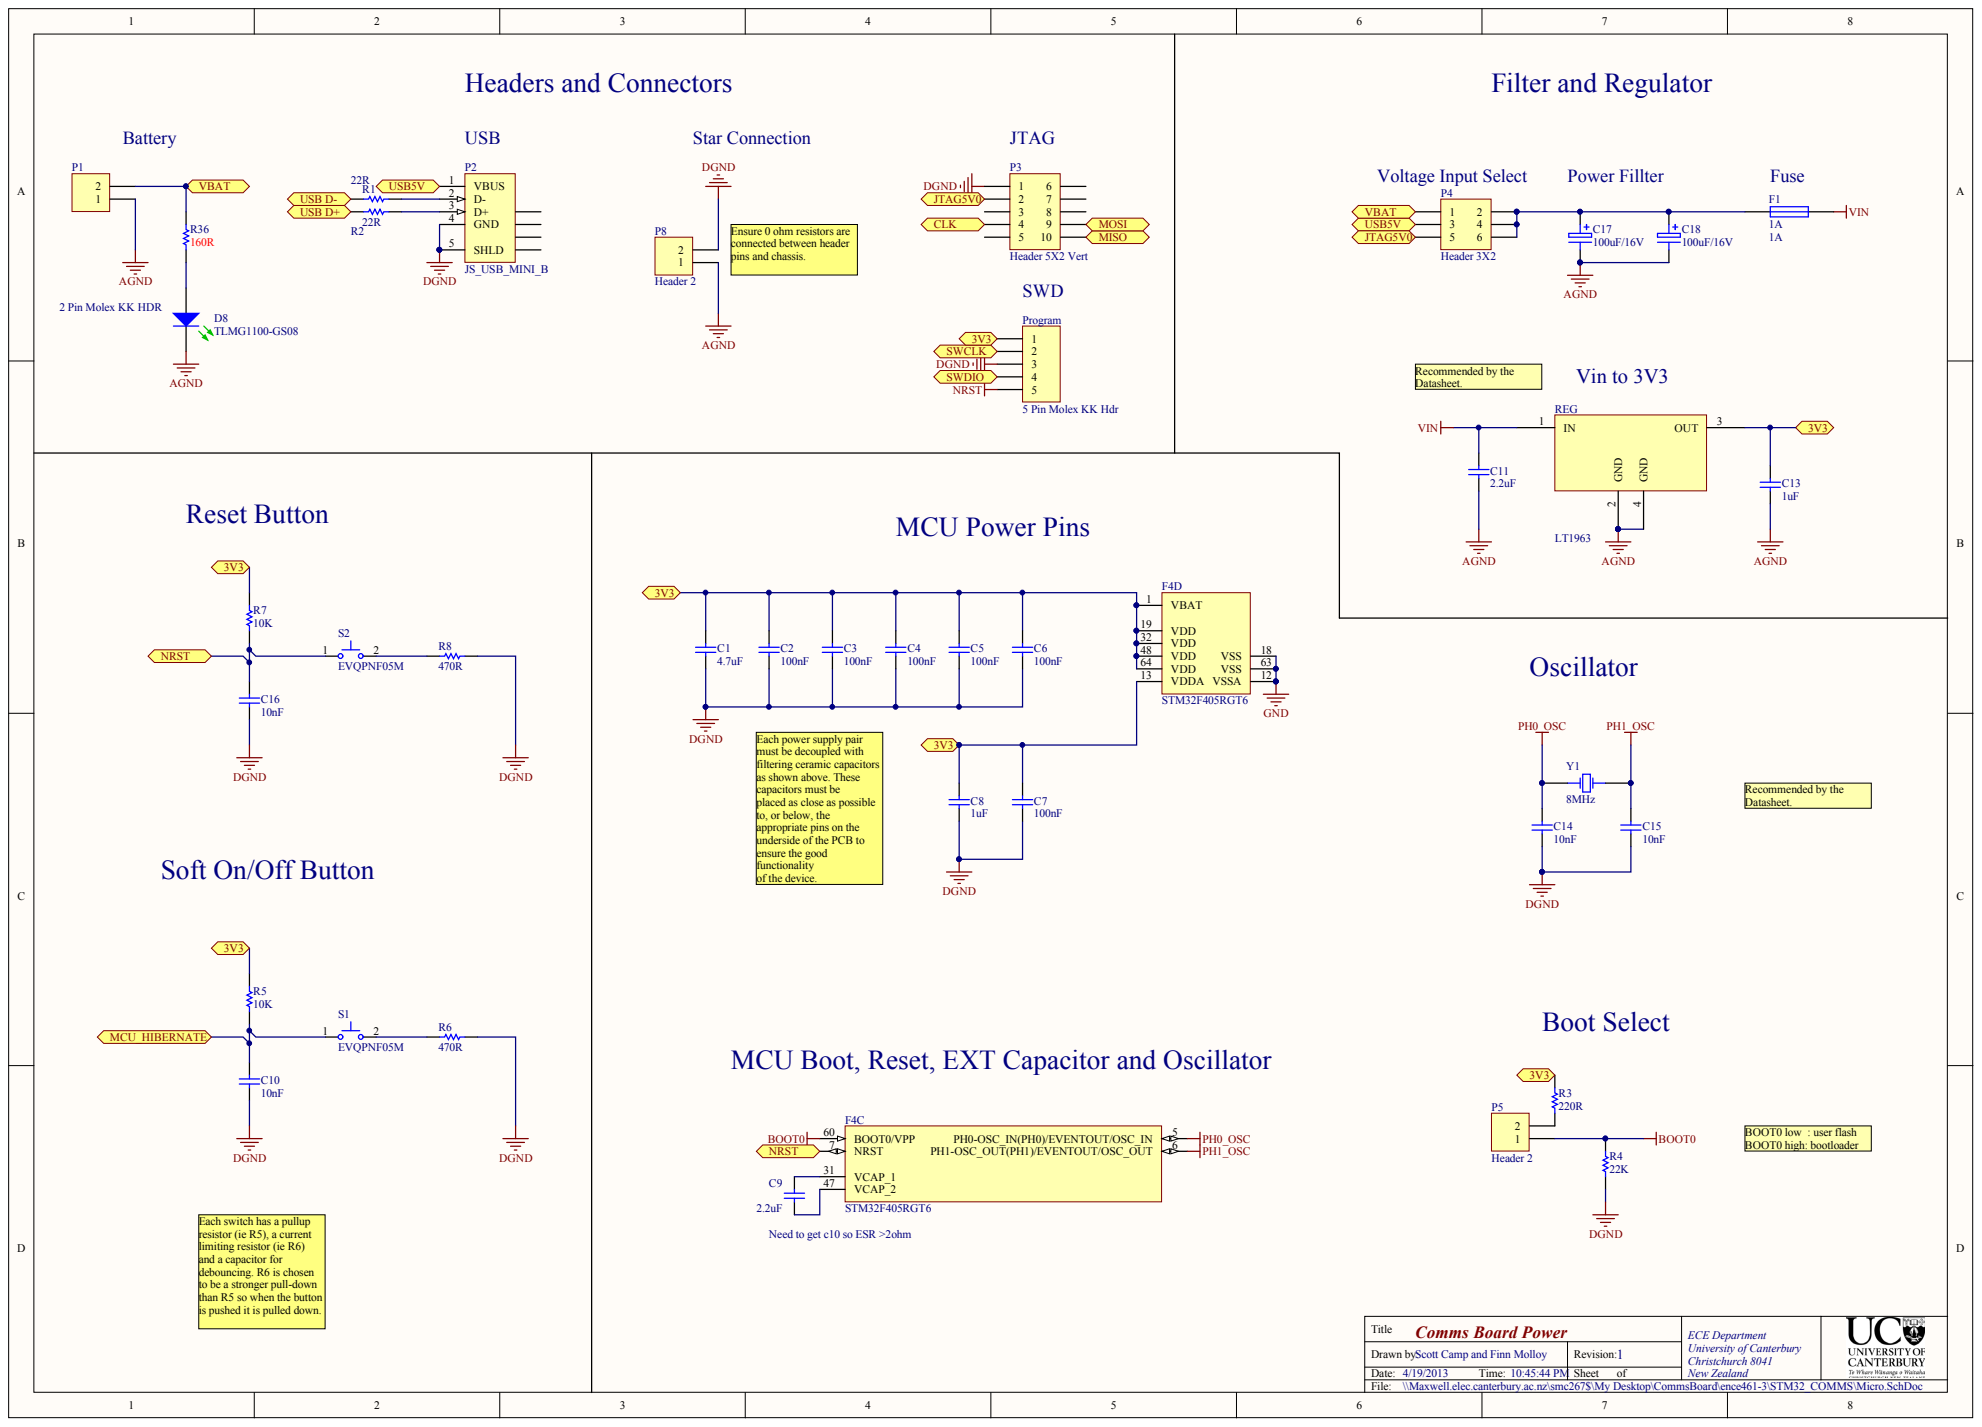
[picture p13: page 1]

Ensure 0 ohm resistors are
connected between header
pins and chassis.

2 Pin Molex KK HDR

Each power supply pair
must be decoupled with
filtering ceramic capacitors
as shown above. These
capacitors must be
placed as close as possible
to, or below, the
appropriate pins on the
underside of the PCB to
ensure the good
functionality
of the device.

Soft On/Off Button

MCU Boot, Reset, EXT Capacitor and Oscillator

Each switch has a pullup
resistor (ie R5), a current
limiting resistor (ie R6)
and a capacitor for
debouncing. R6 is chosen
to be a stronger pull-down
than R5 so when the button
is pushed it is pulled down.

Need to get c10 so ESR >2ohm

Title Comms Board Power | ECE Department University of Canterbury Christchurch 8041 New Zealand
Drawn by: Scott Camp and Finn Molloy | Revision: 1

Date: 4/19/2013 Time: 10:45:44 PM | Sheet of

\\Maxwell.elec.canterbury.ac.nz\smc267$\My Desktop\CommsBoard\ence461-3\STM32_COMMS\Micro.SchDoc

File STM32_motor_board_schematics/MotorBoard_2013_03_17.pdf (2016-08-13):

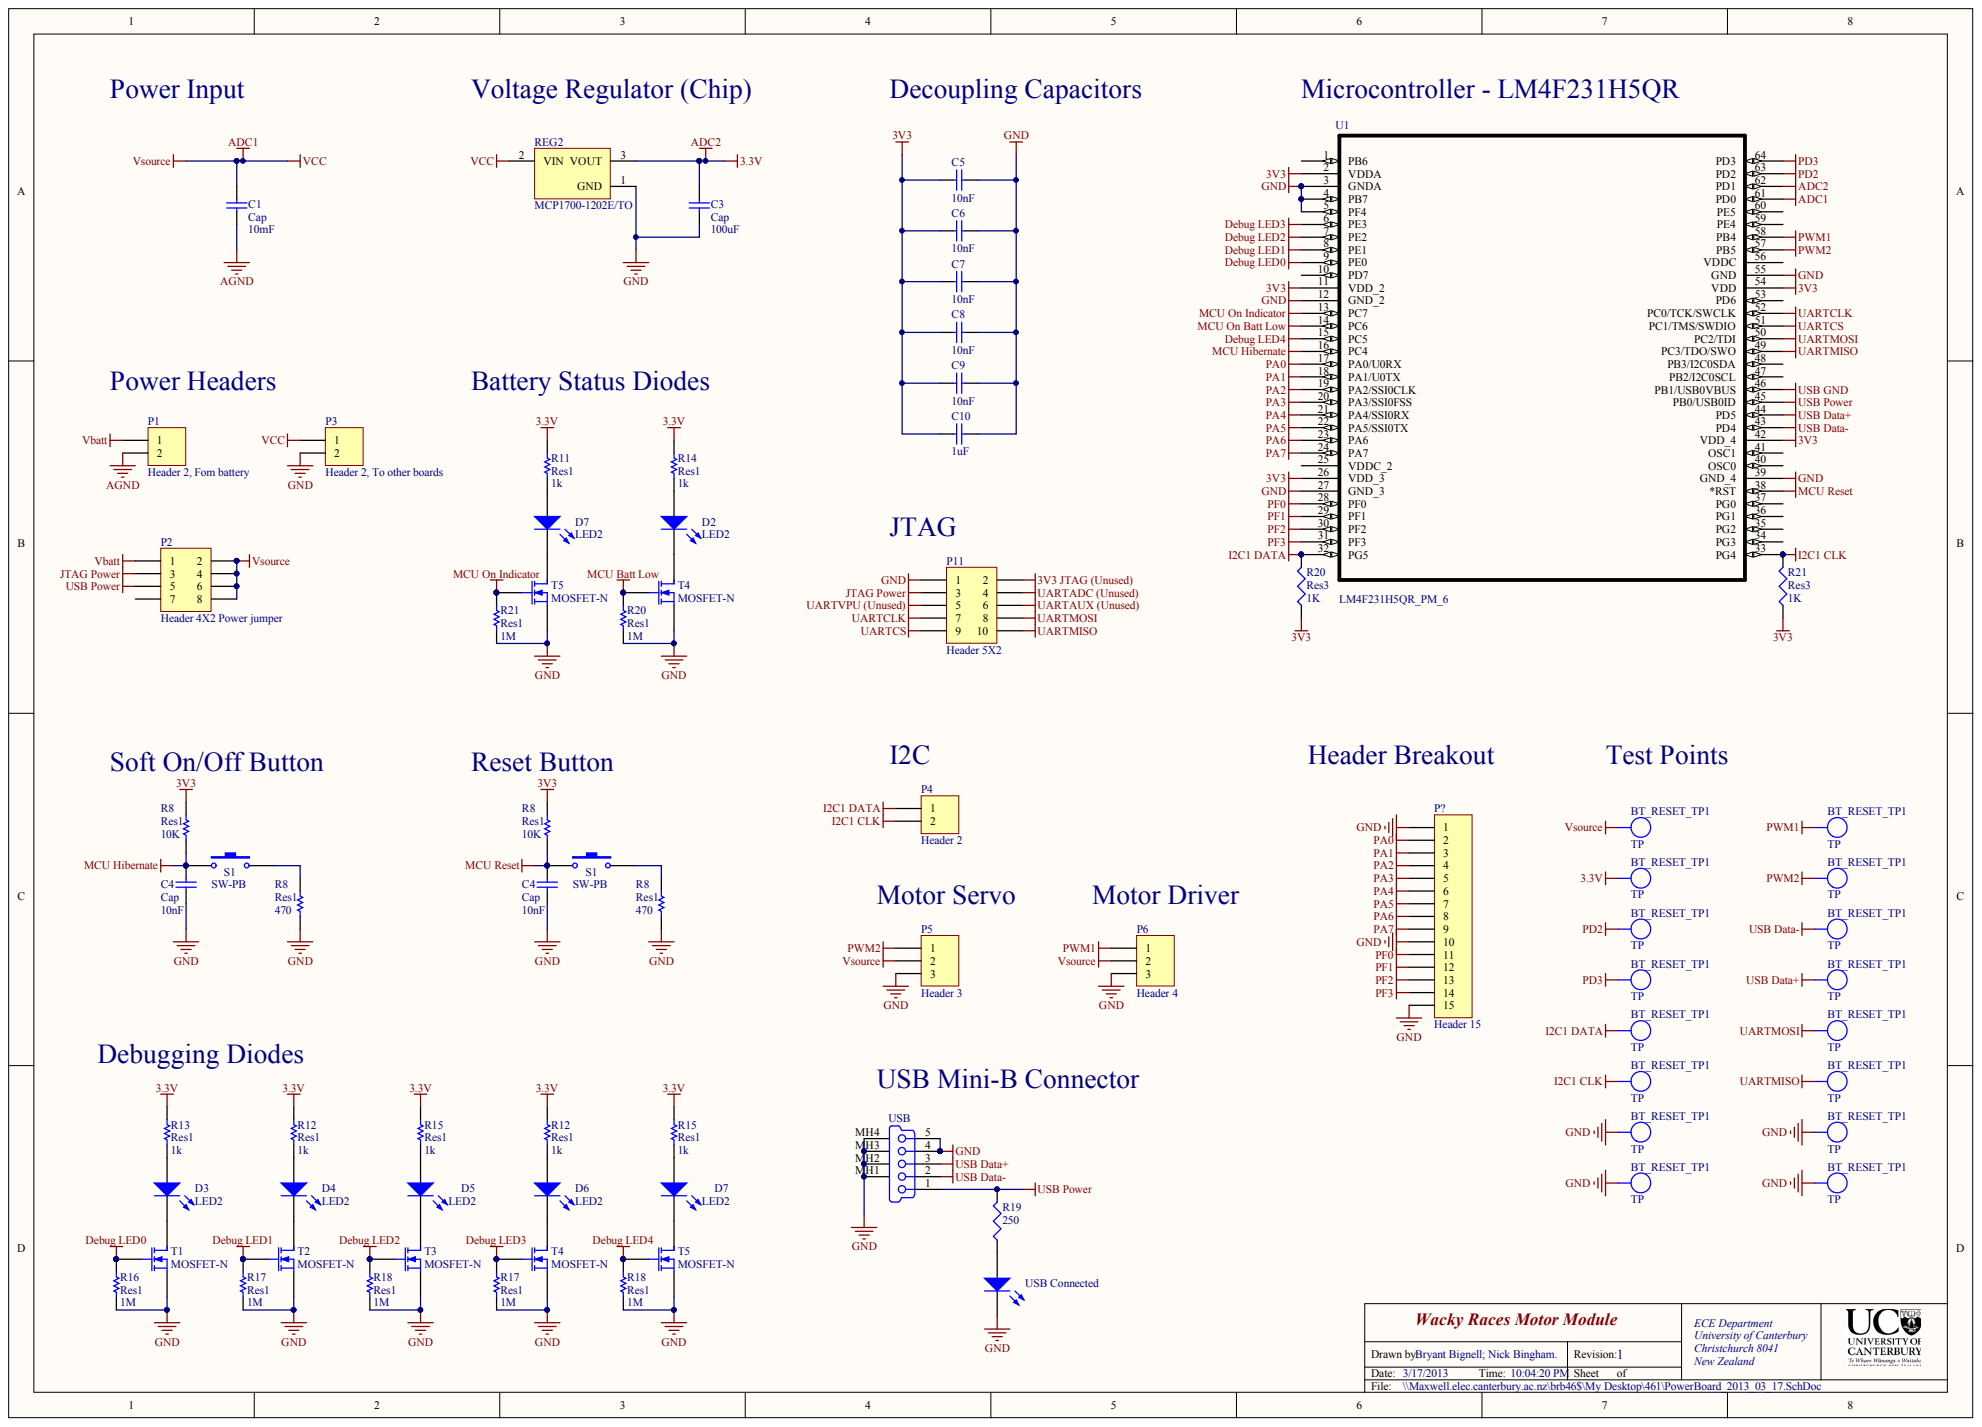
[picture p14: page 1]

1 2 | 5
1 3 | 5 2
1 4 | 5 1
1 5 | 5 0

2 7 | 3
2 8 | 3 7

Soft On/Off Button

Wacky Rac es Motor Module | ECE Dep a rtme n t Univ e rsity of Ca nte rb u ry Ch ristc h u r c h 8 0 4 1 New Ze ala n d

Drawn b y Bry : ant Big n ell; Nic k Bin g h am. | Re visio n : 1

Date : 3/1 7/2 0 1 3 Time : 1 0:0 4:2 0 P M | S h e e t o f

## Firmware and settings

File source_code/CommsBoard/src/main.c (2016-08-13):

/**
*****************************************************************************
**
**  File        : main.c
**
**  Abstract    : main function.
**
**  Functions   : main
**
**  Environment : Atollic TrueSTUDIO(R)
**                STMicroelectronics STM32F4xx Standard Peripherals Library
**
*****************************************************************************
*/

/* Includes */
#include "main.h"
#include "stm32f4xx.h"
#include "ir.h"

#include "uart.h"
#include "led.h"
#include "button.h"
#include "timer.h"
#include "standby.h"
#include "i2c.h"
#include "debug_gpio.h"

#define BATMAN 1

//static uint8_t lastButtonStatus = RESET;
static u16 currentLed = 0;
static u32 currentTime = 0;

int wheel_angle = 0;
int motor_speed = 0;
long unsigned int sysTick;

void init_all()
{


	led_init();
	button_init();
	timer_init();
	standby_init();
	uart_init();
	debug_gpio_init();
	i2c_init();

	led_on(STATUS_LED_ON);
}

int main() {
    init();
    uint16_t ir_data = 0;

    int i=0;
    init_all();
    while(1){


    	for(i=-100;i<100;i++){
    		i2c_set_speed(i);
    	}

    	for(i=100;i>-100;i--){
    		i2c_set_speed(i);
    	}

    	//uart_send("World\n\r");






    }



    ir_rc5_rx_init();
    //initExtInterrupt();
	//initClkInterrupt();
    while(BATMAN)
    {
    	ir_data = ir_rc5_rx_read();
    	MOTORCONTROL(ir_data);


        //loop();
	}
}

void init() {
    RCC_AHB1PeriphClockCmd(RCC_AHB1Periph_GPIOC, ENABLE);
    GPIO_InitTypeDef gpio;
    GPIO_StructInit(&gpio);
    gpio.GPIO_Mode = GPIO_Mode_OUT;
    gpio.GPIO_Pin = LEDS;
    GPIO_Init(GPIOC, &gpio);


}

void initButton() {
    RCC_AHB1PeriphClockCmd(RCC_AHB1Periph_GPIOA, ENABLE);

    GPIO_InitTypeDef gpio;
    GPIO_StructInit(&gpio);
    gpio.GPIO_Mode = GPIO_Mode_IN;
    gpio.GPIO_Pin = GPIO_Pin_0;
    GPIO_Init(GPIOA, &gpio);
}

void initButtonLED() {
	RCC_AHB1PeriphClockCmd(RCC_AHB1Periph_GPIOC, ENABLE);
	GPIO_InitTypeDef gpio;
	GPIO_StructInit(&gpio);
	gpio.GPIO_Mode = GPIO_Mode_OUT;
	gpio.GPIO_Pin = GPIO_Pin_14;
	GPIO_Init(GPIOC, &gpio);
}

void loop() {
	__NOP();
    //static uint32_t counter = 0;

    //uint8_t currentButtonStatus = GPIO_ReadInputDataBit(GPIOA, GPIO_Pin_0);

	//if (lastButtonStatus != currentButtonStatus && currentButtonStatus != RESET) {
	//	GPIO_ToggleBits(GPIOC, GPIO_Pin_14);
	//}
    //lastButtonStatus = currentButtonStatus;

    //++counter;

    //GPIO_ResetBits(GPIOC, LEDS);
    //GPIO_SetBits(GPIOC, LED[counter % 4]);

    //delay(50);
	uint16_t data = 0;
	data = ir_rc5_rx_read();

	if (data == 12320) {
		GPIO_ToggleBits(GPIOC, GPIO_Pin_0);
	}
	if (data == 12304) {
		GPIO_ToggleBits(GPIOC, GPIO_Pin_3);
	}
	if (data == 12321) {
		GPIO_ToggleBits(GPIOC, GPIO_Pin_1);
	}
	if (data == 12305) {
		GPIO_ToggleBits(GPIOC, GPIO_Pin_2);
	}
}

void delay(uint32_t ms) {
    ms *= 3360;
    while(ms--) {
        __NOP();
    }
}

void toggleLed(void) {
    if (currentTime % 200 == 0) {
        GPIO_ToggleBits(GPIOC, LED[currentLed]);
    }
}



void initExtInterrupt() {
    EXTI_InitTypeDef   EXTI_InitStructure;

    RCC_APB2PeriphClockCmd(RCC_APB2Periph_SYSCFG, ENABLE);
    SYSCFG_EXTILineConfig(EXTI_PortSourceGPIOA,EXTI_PinSource0);
    EXTI_InitStructure.EXTI_Line = EXTI_Line0;
    EXTI_InitStructure.EXTI_Mode = EXTI_Mode_Interrupt;
    EXTI_InitStructure.EXTI_Trigger = EXTI_Trigger_Rising;
    EXTI_InitStructure.EXTI_LineCmd = ENABLE;
    EXTI_Init(&EXTI_InitStructure);

    NVIC_InitTypeDef NVIC_InitStructure;

    NVIC_InitStructure.NVIC_IRQChannel = EXTI0_IRQn;
    NVIC_InitStructure.NVIC_IRQChannelPreemptionPriority = 0x0F;
    NVIC_InitStructure.NVIC_IRQChannelSubPriority = 0x0F;
    NVIC_InitStructure.NVIC_IRQChannelCmd = ENABLE;
    NVIC_Init(&NVIC_InitStructure);
}


void switchLed(void) {
    GPIO_ResetBits(GPIOC, LED[currentLed]);

    currentLed++;
    if (currentLed > 3) {
        currentLed = 0;
    }
}


void MOTORCONTROL(data)
{
	if (data == 12320)
    {
       	if(motor_speed>=0)
       	{
       	   	motor_speed += 2;
       	}
       	else
       	{
       		motor_speed = 0;
       	}
    }
    else if (data == 12304)
    {
      	wheel_angle -= 2;
    }
    else if (data == 12321)
    {
      	if(motor_speed<=0)
       	{
       		motor_speed -= 2;
       	}
      	else
      	{
      		motor_speed = 0;
      	}
    }
    else if (data == 12305)
    {
       	wheel_angle += 2;
    }
    else
    {
       	if(motor_speed>0)
       	{
       		motor_speed -=1;
       	}
       	else if(motor_speed<0)
       	{
       		motor_speed +=1;
       	}
    }
}
